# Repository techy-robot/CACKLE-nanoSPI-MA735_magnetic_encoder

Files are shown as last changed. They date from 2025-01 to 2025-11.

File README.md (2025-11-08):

---
modified: 2025-11-07T22:07:46-07:00
---

# nanoSPI MA735 magnetic encoder

> [!TIP]
> This board is part of a larger modular control board ecosystem, [CACKLE](https://github.com/techy-robot/CACKLE)

This is a super compact SPI magnetic encoder, with the flex cable being 2.4mm wide and 100mm long, and the tip around 5.6mm diameter. It is quite simple, and supports on shaft or side-shaft mounting with correction.

It supports a max of 25mhz bus speed, though practically speaking this is closer to 20mhz. It supports SPI mode 0 or 3, detecting automatically.

The sensor itself, MagAlpha MA735, has some quirks to it. It is variable resolution ranging from 9 to 13 bit which is inversely proportional to its speed. If you want the max measurement speed at 60k rpm, then you will have to read 9-bit angles. This is all dictated by the Filter Window setting, resolution and speed are derived from this setting.

This can be used as a template for other nanoSPI sensors, or cables.

Also, the connectors for these sensors with a 0.35mm pitch are SUPER finicky to actually solder by hand, reflow is 1000% recommended. You will burn the plastic onto a soldering iron in one swipe.

Schematic PDF

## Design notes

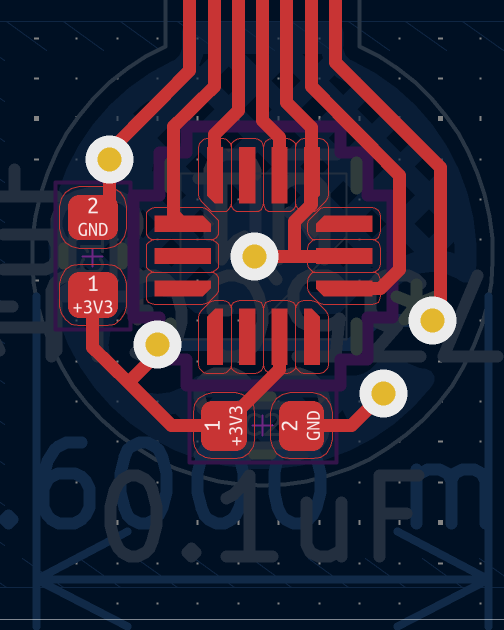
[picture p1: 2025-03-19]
media/MA735 Top.png

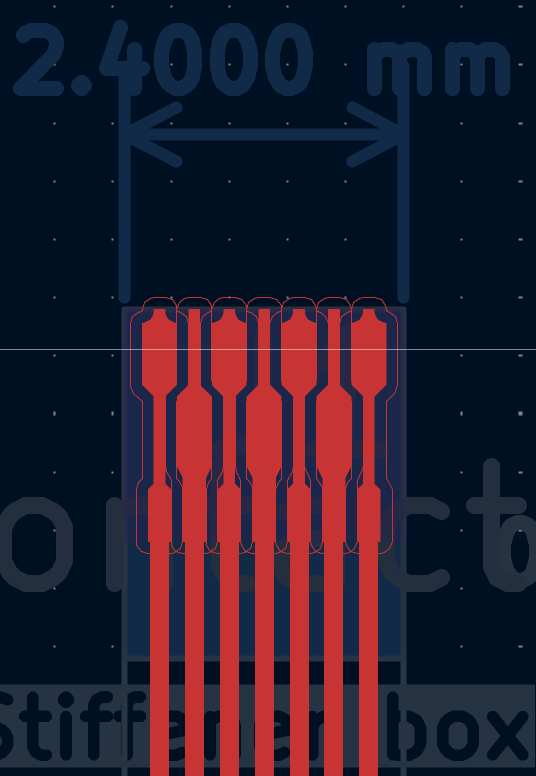
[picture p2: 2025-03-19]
media/nanoSPI cable connector.png

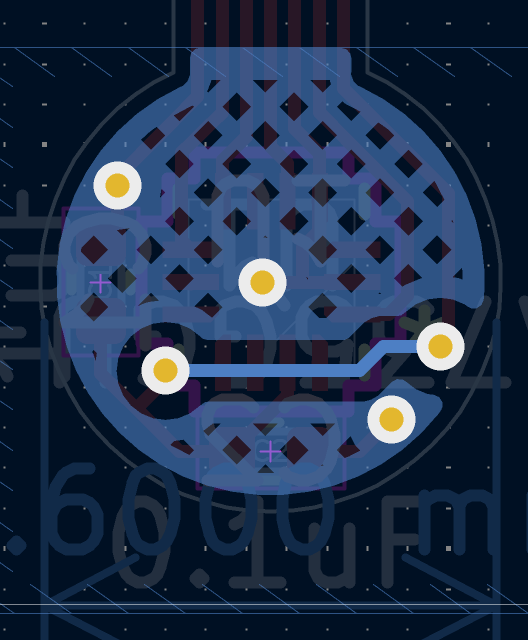
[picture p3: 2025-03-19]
media/MA735 Bottom.png

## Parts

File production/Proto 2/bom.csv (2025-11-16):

Designator | Footprint | Quantity | Value | LCSC Part #
C1 | 0402 | 1 | 1uF | C52923
C2 | 0402 | 1 | 0.1uF | C1525
J1 | 7pin_fpc_contact_0.3mmptich | 1 | FPC contacts 0.3mm
U1 | UTQFN-14_MA735_MNP | 1 | MA735GGU-Z | C17233427

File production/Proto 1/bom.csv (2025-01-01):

Designator | Footprint | Quantity | Value | LCSC Part #
C1 | 0402 | 1 | 1uF | C52923
C2 | 0402 | 1 | 0.1uF | C1525
U1 | UTQFN-14_MA735_MNP | 1 | MA735GGU-Z | C17233427

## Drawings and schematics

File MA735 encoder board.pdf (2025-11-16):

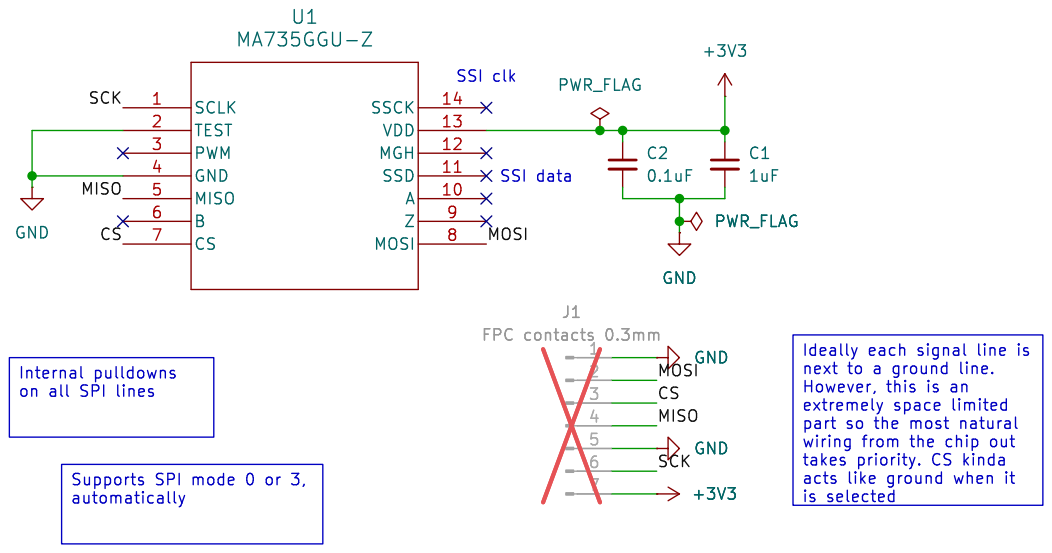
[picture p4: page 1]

Ideally each signal line is next to a ground line. However, this is an

part so the most natural wiring from the chip out

acts like ground when it

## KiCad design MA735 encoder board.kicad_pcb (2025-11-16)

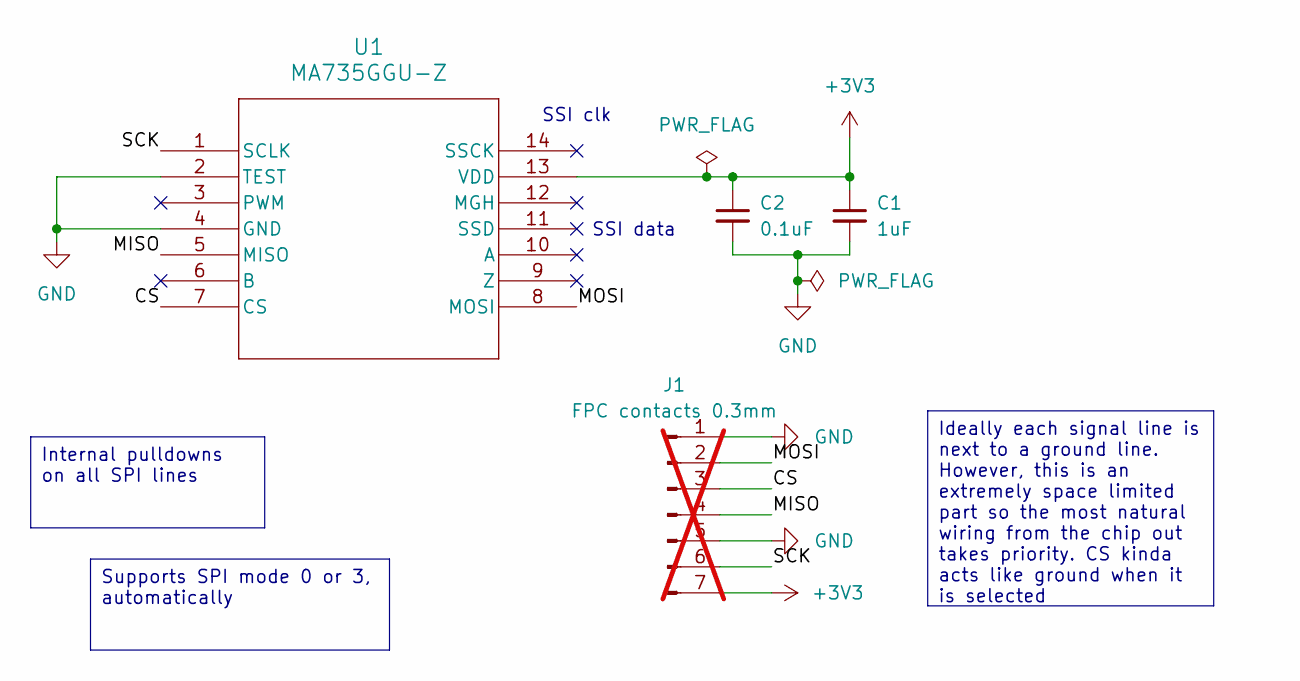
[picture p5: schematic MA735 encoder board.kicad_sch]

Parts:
C1: 1uF; C_0402_1005Metric; LCSC C52923
C2: 0.1uF; C_0402_1005Metric; LCSC C1525
J1: FPC contacts 0.3mm; 7pin_fpc_contact_0.3mmptich; not fitted
U1: MA735GGU-Z; UTQFN-14_MA735_MNP; LCSC C17233427

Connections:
+3V3: C1.1, C2.1, J1.7, U1.13 (VDD)
/CS: J1.3, U1.7 (CS)
/MISO: J1.4, U1.5 (MISO)
/MOSI: J1.2, U1.8 (MOSI)
/SCK: J1.6, U1.1 (SCLK)
GND: C1.2, C2.2, J1.1, J1.5, U1.2 (TEST), U1.4 (GND)

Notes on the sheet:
SSI clk
SSI data
Supports SPI mode 0 or 3, automatically
Ideally each signal line is next to a ground line. However, this is an extremely space limited part so the most natural wiring from the chip out takes priority. CS kinda acts like ground when it is selected
Internal pulldowns on all SPI lines

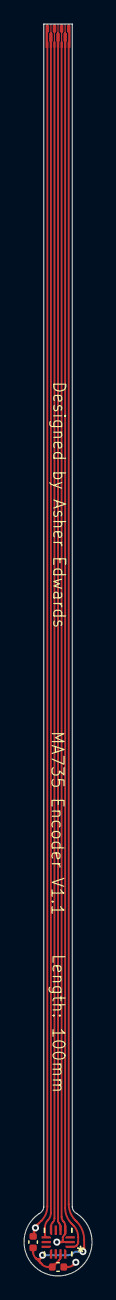
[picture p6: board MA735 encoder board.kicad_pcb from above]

Board: 2 copper layers, 5.7 x 105.5 mm, 4 parts (0 on the bottom side), 6 nets.

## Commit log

2024-12-31 Added MA735 encoder nanoSPI device
    This is a new line for what the 7 pin FPC SPI cables are.
    [MA735 encoder board-B_Cu.gbr, MA735 encoder board-B_Mask.gbr, MA735 encoder board-B_Paste.gbr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]
2025-01-01 Exported Gerbers for MA735 encoder
    [MA735 encoder board Main BOM.csv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]
2025-01-01 Updated files for JLC DFM checks
    [MA735 encoder board.kicad_pcb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]
2025-01-02 Added schematic PDFs for all boards
2025-01-04 Added gerber zip files
2025-01-13 Changed link names for schematic embeds not displayin
    In Obsidian I can see the pdf embeds perfectly fine, but Github doesn't want to show embedded PDFs. I changed the link alias to "Schematic PDF" so people know what the link is when it doesn't display
2025-05-06 Updated MA735 encoder
    [MA735 encoder board.kicad_pcb, MA735 encoder board.kicad_sch]
2025-05-06 Updated MA735 readme and production
    [MA735 encoder board.kicad_pcb]
2025-10-10 Moved all current production files to Proto 1.
    I haven't made a 2nd prototype yet
    [MA735 encoder board-B_Cu.gbl, MA735 encoder board-B_Mask.gbs, MA735 encoder board-B_Paste.gbp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]
2025-11-16 Tweaked schematic layout to be slightly less jank
    [MA735 encoder board.kicad_sch]
2025-11-16 Added license notes
    [MA735 encoder board.kicad_pcb]
2025-11-16 Updated FPC connector to avoid clearance issues and be more consistant
    [MA735 encoder board.kicad_pcb]
2025-11-16 Added Credit on silkscreen
    [MA735 encoder board.kicad_pcb]
2025-11-16 Added stiffener behind encoder
    [MA735 encoder board.kicad_pcb]
2025-11-16 Updated graphics
    [MA735 encoder board.kicad_pcb]
2025-11-16 Added teardrops
    [MA735 encoder board.kicad_pcb]
2025-11-16 Rounded Tracks
    [MA735 encoder board.kicad_pcb]
2025-11-16 Fixed errors in DRC
    [MA735 encoder board.kicad_pcb]
2025-11-16 Added production files
    [bom.csv, designators.csv, positions.csv]
2025-11-16 Updated schematic pdf
2025-11-16 Changed to Coverlay defined pads
    [MA735 encoder board.kicad_pcb]

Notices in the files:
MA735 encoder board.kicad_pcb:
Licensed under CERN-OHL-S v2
